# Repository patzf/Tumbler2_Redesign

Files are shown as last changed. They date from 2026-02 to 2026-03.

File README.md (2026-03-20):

# Tumbler 2 `ultra-low-cost`

Single USB port variant of the `Tumbler 2` redesign, optimized for maximum cost reduction.

## Changes

| Original Design | Redesign Improvement |
| --- | --- |
| Unfused battery supply | Add slow-blow fuse directly at connector |
| 5 V to 3.3 V LDO regulator | 5 V to 3.3 V buck converter |
| WROOM module with ESP32-D0WD-V3 | WROOM module with ESP32-S3 |
| CH340 for USB-UART Bridge | Directly connect to ESP32 DP/DN |
| 100 nF capacitors on BTN and GPIO0 | Removed unnecessary capacitors on BTN and GPIO0  |
| USB-C shield directly to signal GND  | Low impedance 100nF to avoid ground loops |
| Use Obsolete MPU6050 breakout module | Use LSM6DSV directly on PCB |
| Use TB6612FNG breakout module | Use 2x TB67H450FNG directly on PCB |
| 5 V ECHO signal directly to ESP32 | Voltage divider to 3.3 V ESP32 GPIO |
| 5 V Encoder signal directly to ESP32 | Voltage divider to 3.3 V ESP32 GPIO |
| No local decoupling for WS2812B LEDs | Added proper local bypass capacitors for WS2812B |

## Discarded Ideas

| Idea | Reason |
| --- | --- |
| On-board charging circuit (IP5306, BQ25887RGER) | Not required. External USB charger included with battery  |
| Additional LDO for clean 3.3 V rail | Not necessary. ESP32-WROOM internal VCC/VCCA already tied |

## Layout Options

| Layout A | Layout B | Layout C |
| --- | --- | --- |
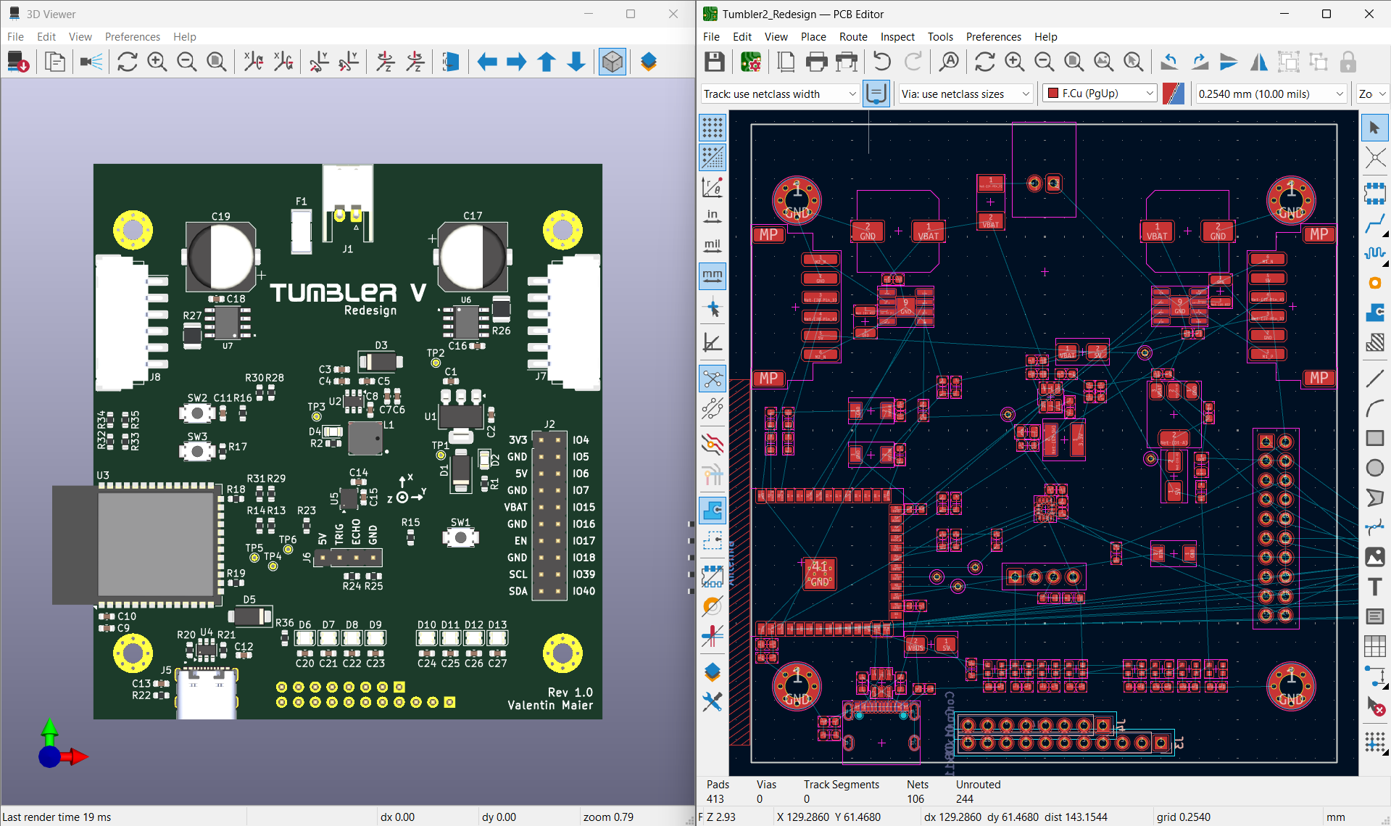
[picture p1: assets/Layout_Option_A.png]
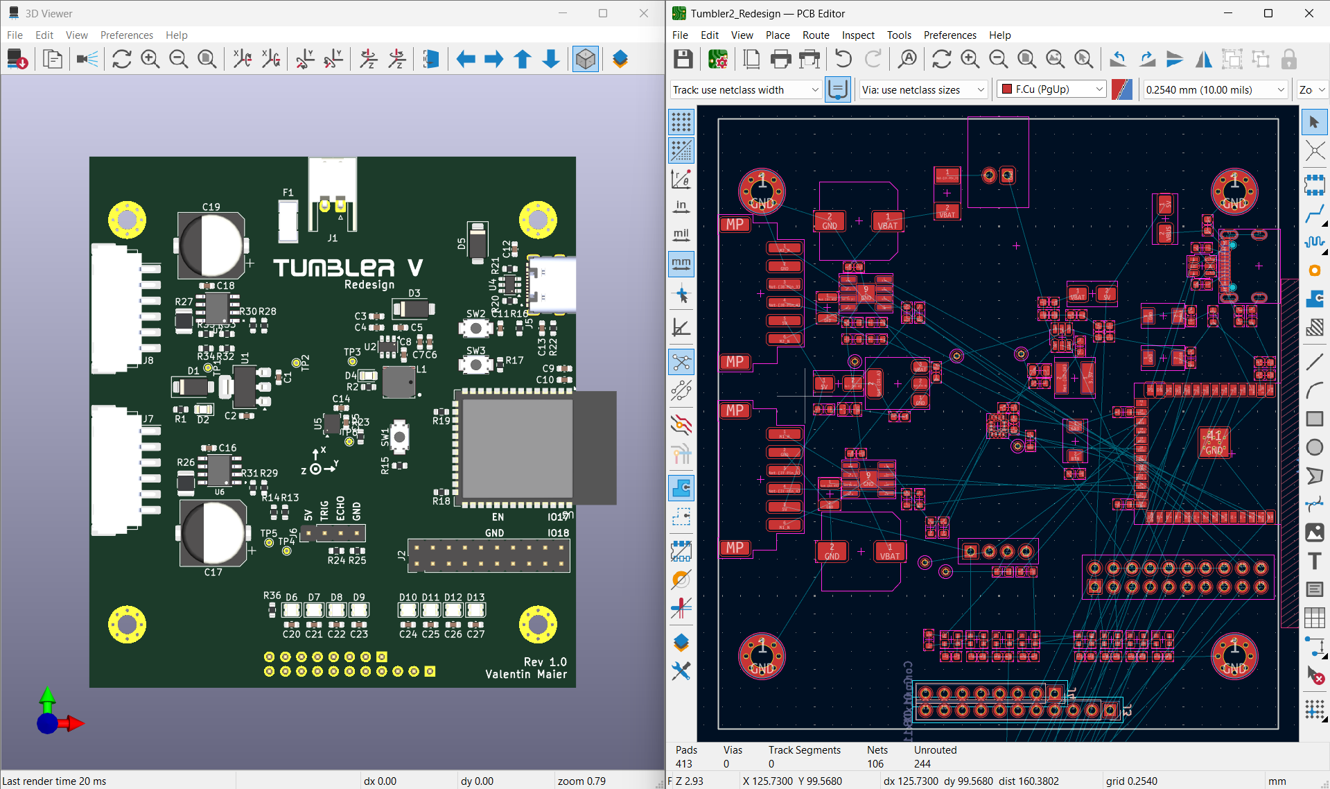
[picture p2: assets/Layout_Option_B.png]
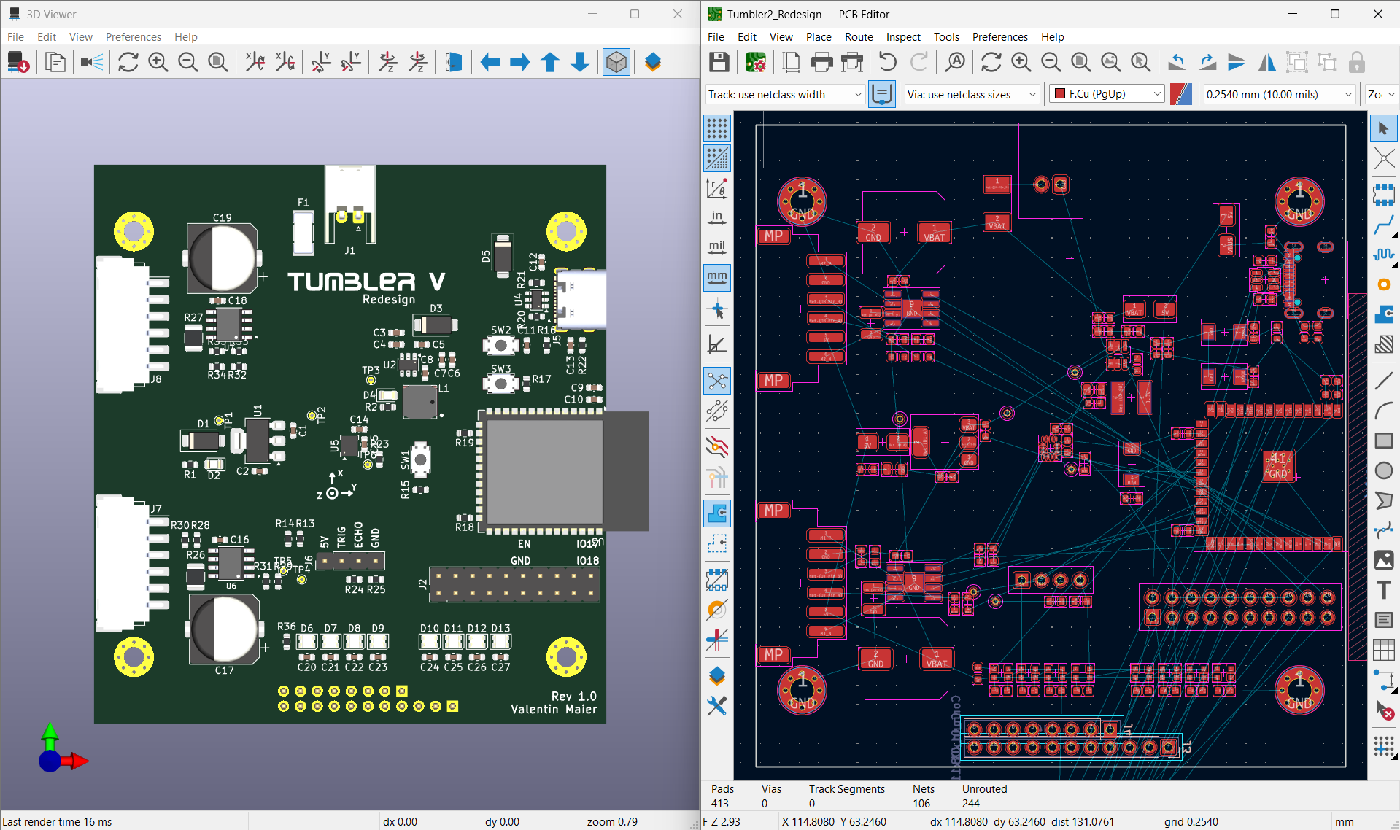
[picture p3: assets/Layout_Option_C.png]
| <br><sub>Preferred option</sub> | <br><sub>Left–right separation</sub> | <br><sub>Looser version of B</sub> |

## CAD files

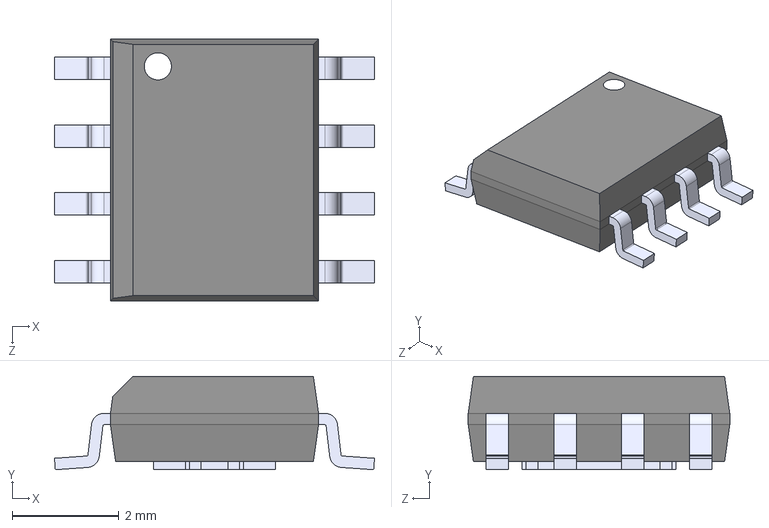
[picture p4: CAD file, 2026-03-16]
Tumbler2_Models/TB67H450FNG_EL.step
6.00 x 1.75 x 4.90 mm

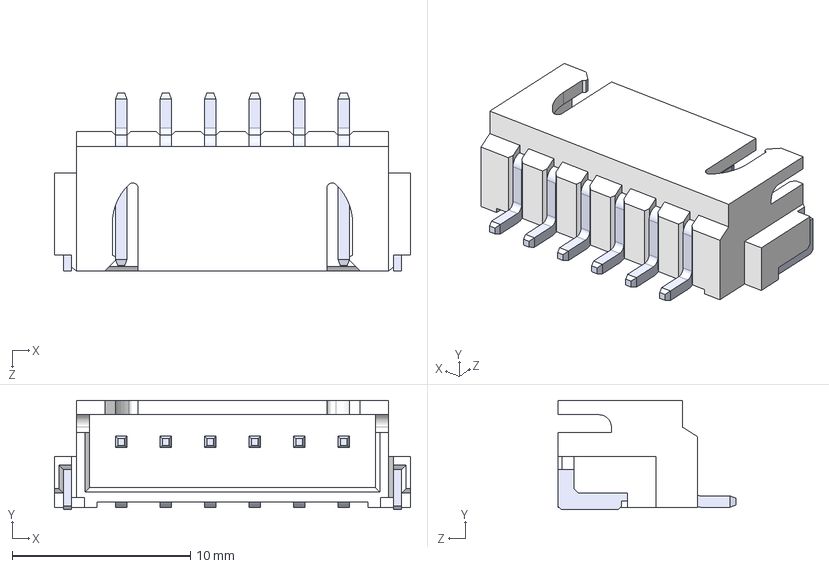
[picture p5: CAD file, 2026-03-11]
Tumbler2_Models/S6B-XH-SM4-TB-LF-SN.step
20.0 x 6.12 x 10.0 mm
SxB-XH-SM4-TB_6
pin^SxB-XH-SM4-TB Ass x 6

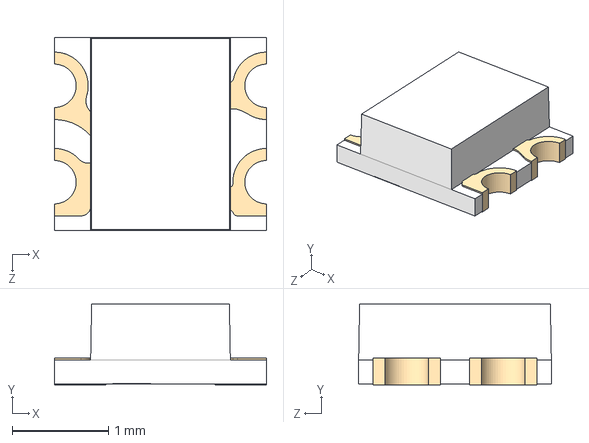
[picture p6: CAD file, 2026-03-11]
Tumbler2_Models/WS2812B-2020.step
2.20 x 0.84 x 2.00 mm

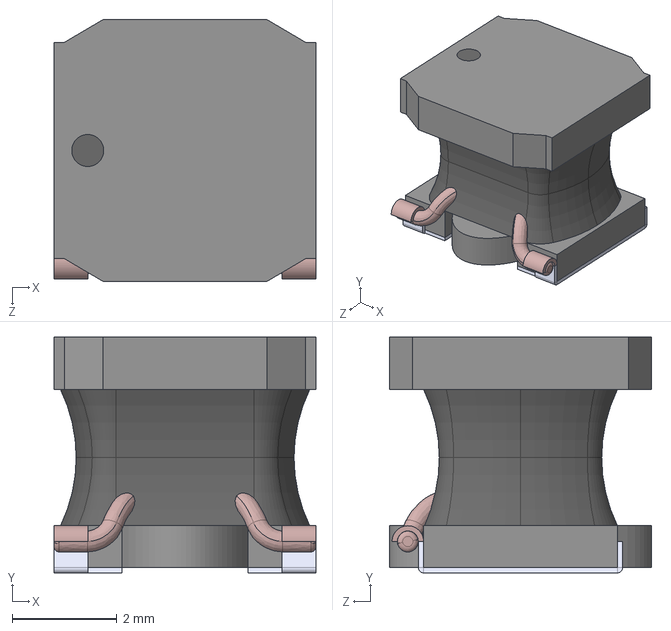
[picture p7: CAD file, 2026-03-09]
Tumbler2_Models/VLS5045EX-4R7M.step
5.00 x 4.50 x 5.00 mm

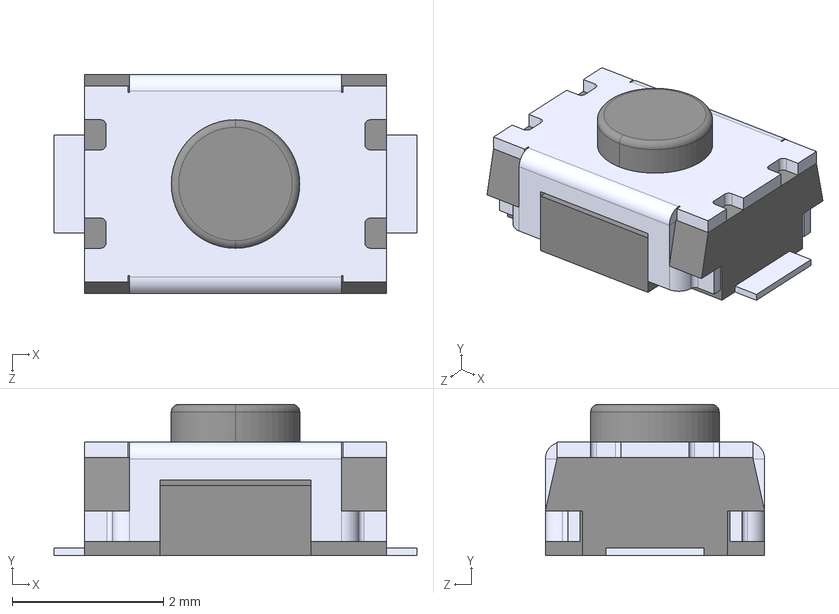
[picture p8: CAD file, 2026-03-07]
Tumbler2_Models/TS-1088-AR02016.step
4.80 x 2.00 x 2.90 mm

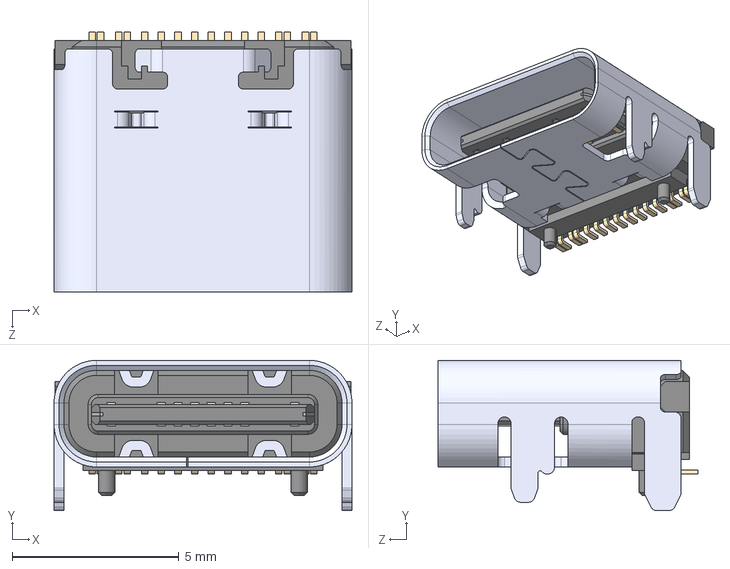
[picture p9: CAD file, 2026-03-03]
Tumbler2_Models/KH-TYPE-C-16P.step
8.94 x 4.51 x 7.81 mm

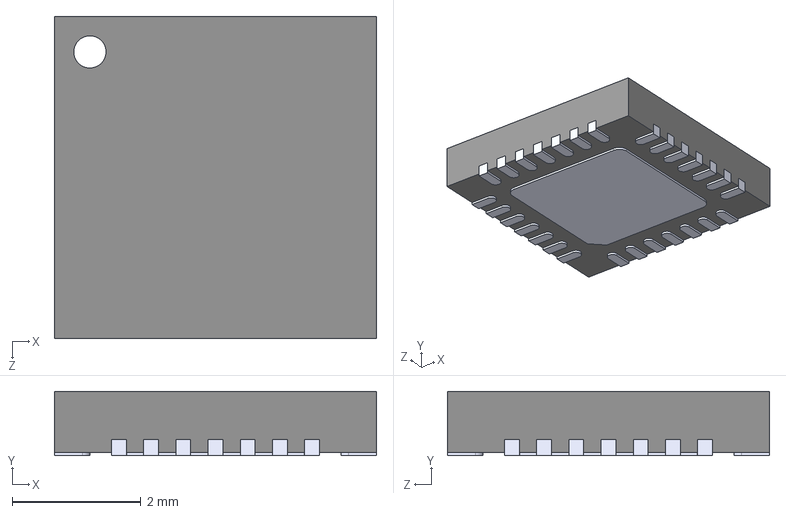
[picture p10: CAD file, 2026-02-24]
Tumbler2_Models/QFN50P500X500X100-29N.step
5.00 x 1.00 x 5.00 mm

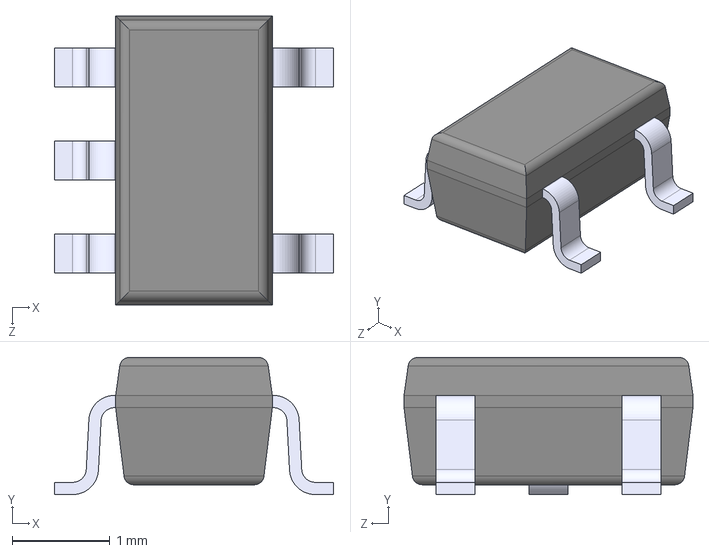
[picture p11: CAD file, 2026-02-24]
Tumbler2_Models/SOT95P285X130-5N.step
2.85 x 1.40 x 2.95 mm

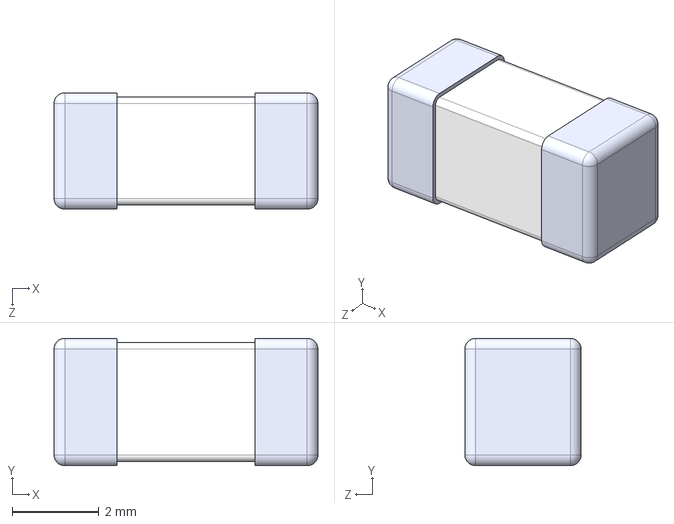
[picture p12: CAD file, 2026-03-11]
Tumbler2_Models/0452005.MRL.step
6.10 x 2.94 x 2.69 mm

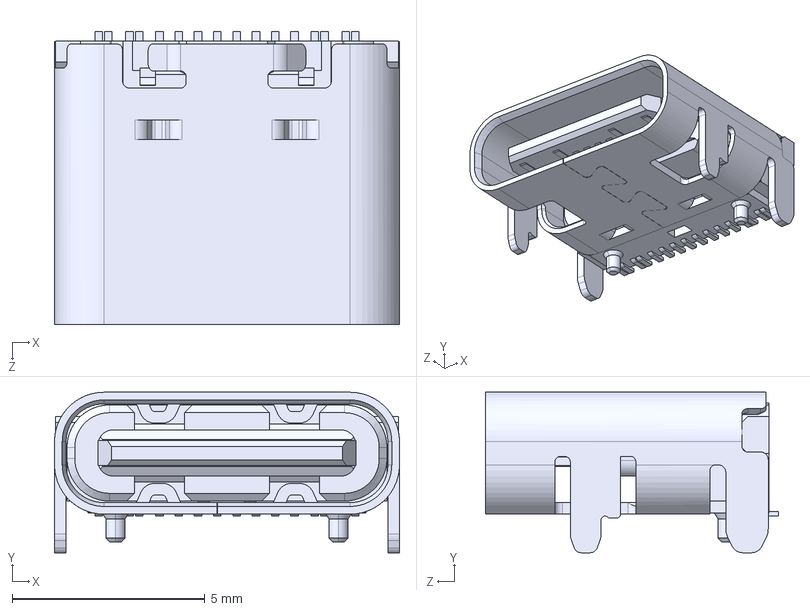
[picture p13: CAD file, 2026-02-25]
Tumbler2_Models/10155435-00011LF.step
8.94 x 4.16 x 7.60 mm

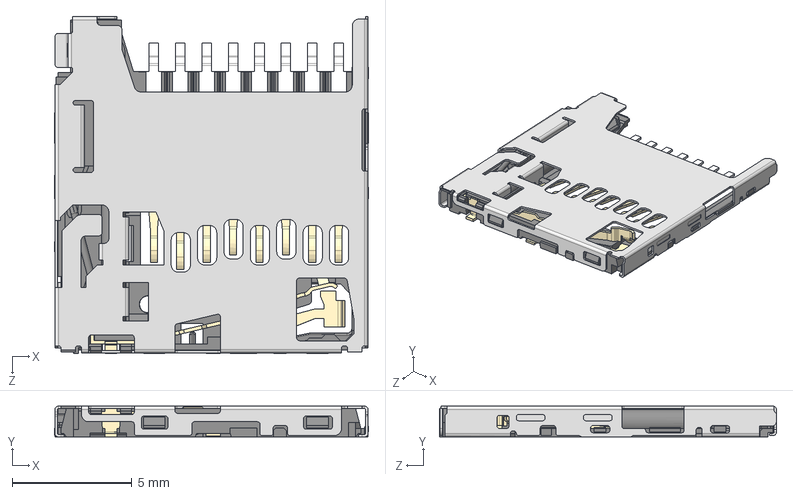
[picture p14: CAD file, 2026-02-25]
Tumbler2_Models/503398-1892.step
13.1 x 1.28 x 14.1 mm

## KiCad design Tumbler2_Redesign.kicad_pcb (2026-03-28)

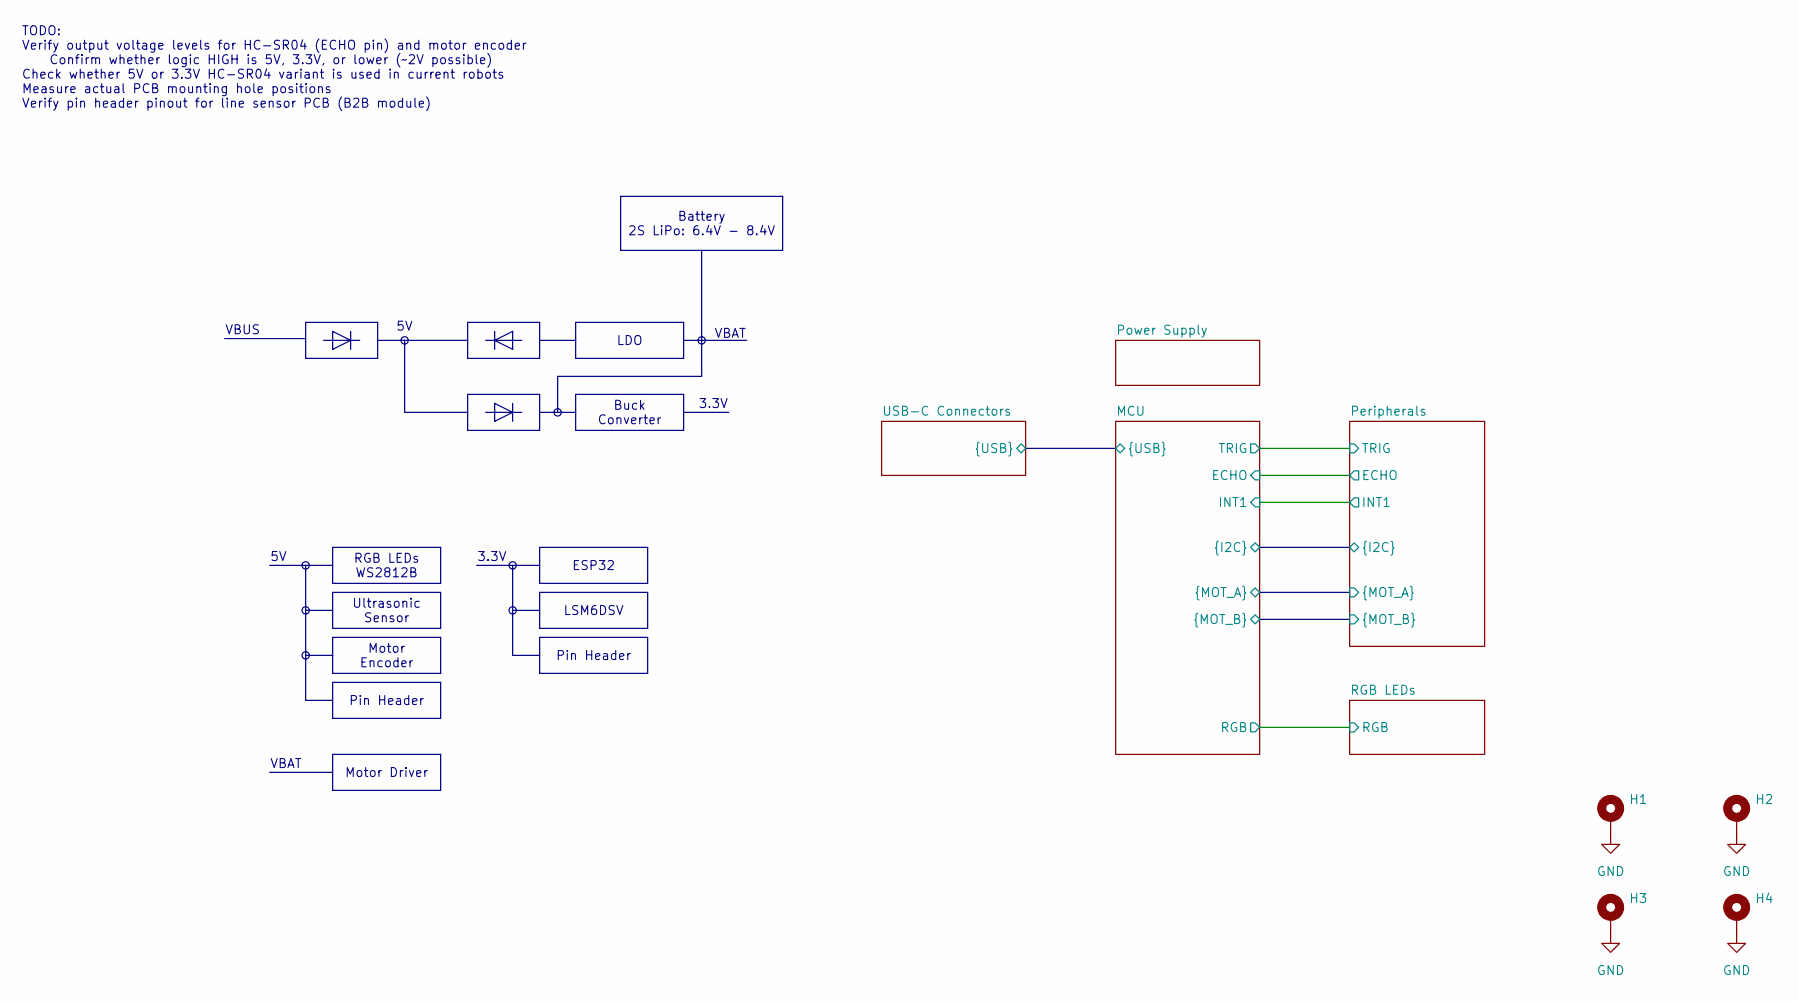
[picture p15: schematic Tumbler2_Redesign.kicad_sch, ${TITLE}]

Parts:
H1, H2, H3, H4: MountingHole_Pad; MountingHole_3mm_Pad_Via

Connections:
GND: H1.1, H2.1, H3.1, H4.1; also elsewhere on the board

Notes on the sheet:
TODO: Verify output voltage levels for HC-SR04 (ECHO pin) and motor encoder Confirm whether logic HIGH is 5V, 3.3V, or lower (~2V possible) Check whether 5V or 3.3V HC-SR04 variant is used in current robots Measure actual PCB mounting hole positions Verify pin header pinout for line sensor PCB (B2B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
VBUS
3.3V
VBAT
Motor Encoder
LSM6DSV
RGB LEDs WS2812B
Motor Driver
Pin Header
Buck Converter
ESP32
Battery 2S LiPo: 6.4V - 8.4V
Ultrasonic Sensor
LDO

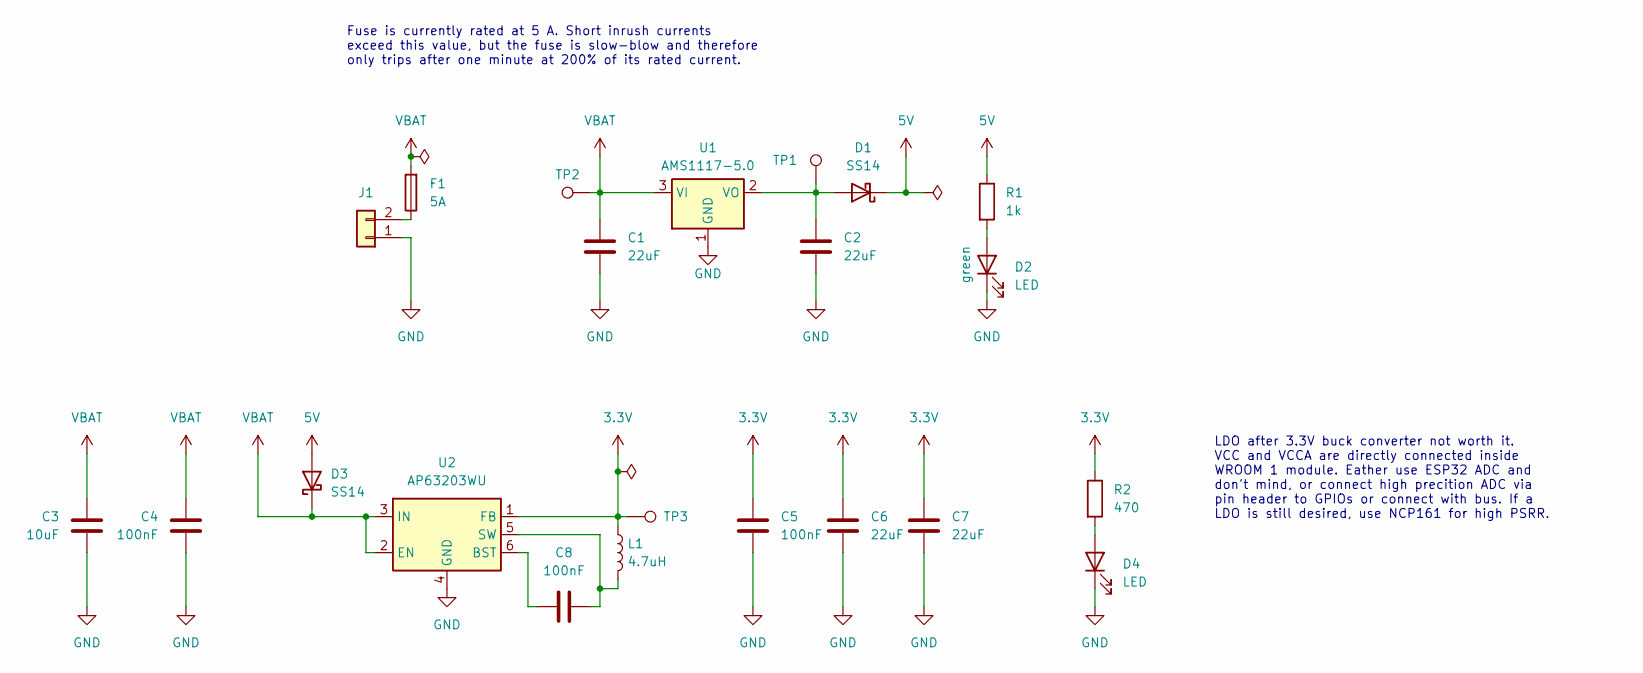
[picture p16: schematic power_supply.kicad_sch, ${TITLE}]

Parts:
C1, C2, C6, C7: 22uF; C_0805_2012Metric; LCSC PN C45783
C3: 10uF; C_0603_1608Metric; LCSC PN C96446
C4, C5, C8: 100nF; C_0603_1608Metric; LCSC PN C14663
D1, D3: SS14; D_SMA; LCSC PN C2480
D2, D4: LED; LED_0805_2012Metric; LCSC PN C2297
F1: 5A; Fuse_Littelfuse-NANO2-451_453; LCSC PN C66503
J1: Conn_01x02; JST_XH_S2B-XH-A-1_1x02_P2.50mm_Horizontal; LCSC PN C163035
L1: 4.7uH; VLS5045EX-4R7M; LCSC PN C307876
R1: 1k; R_0603_1608Metric; LCSC PN C21190
R2: 470; R_0603_1608Metric; LCSC PN C23179
TP1, TP2, TP3: TestPoint; TestPoint_THTPad_D1.0mm_Drill0.5mm
U1: AMS1117-5.0; SOT-223-3_TabPin2; LCSC PN C6187
U2: AP63203WU; TSOT-23-6; LCSC PN C780769

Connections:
3.3V: C5.1, C6.1, C7.1, L1.1, R2.1, TP3.1, U2.1 (FB); also elsewhere on the board
5V: D1.1 (K), D3.2 (A), R1.1; also elsewhere on the board
GND: C1.2, C2.2, C3.2, C4.2, C5.2, C6.2, C7.2, D2.1 (K), D4.1 (K), J1.1, U1.1 (GND), U2.4 (GND); also elsewhere on the board
unnamed: C2.1, D1.2 (A), TP1.1, U1.2 (VO)
unnamed: D2.2 (A), R1.2
unnamed: D4.2 (A), R2.2
unnamed: F1.1, J1.2
unnamed: C8.2, U2.6 (BST)
unnamed: C8.1, L1.2, U2.5 (SW)
VBAT: C1.1, C3.1, C4.1, D3.1 (K), F1.2, TP2.1, U1.3 (VI), U2.2 (EN), U2.3 (IN); also elsewhere on the board

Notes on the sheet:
Fuse is currently rated at 5 A. Short inrush currents exceed this value, but the fuse is slow-blow and therefore only trips after one minute at 200% of its rated current.
LDO after 3.3V buck converter not worth it. VCC and VCCA are directly connected inside WROOM 1 module. Eather use ESP32 ADC and don't mind, or connect high precition ADC via pin header to GPIOs or connect with bus. If a LDO is still desired, use NCP161 for high PSRR.

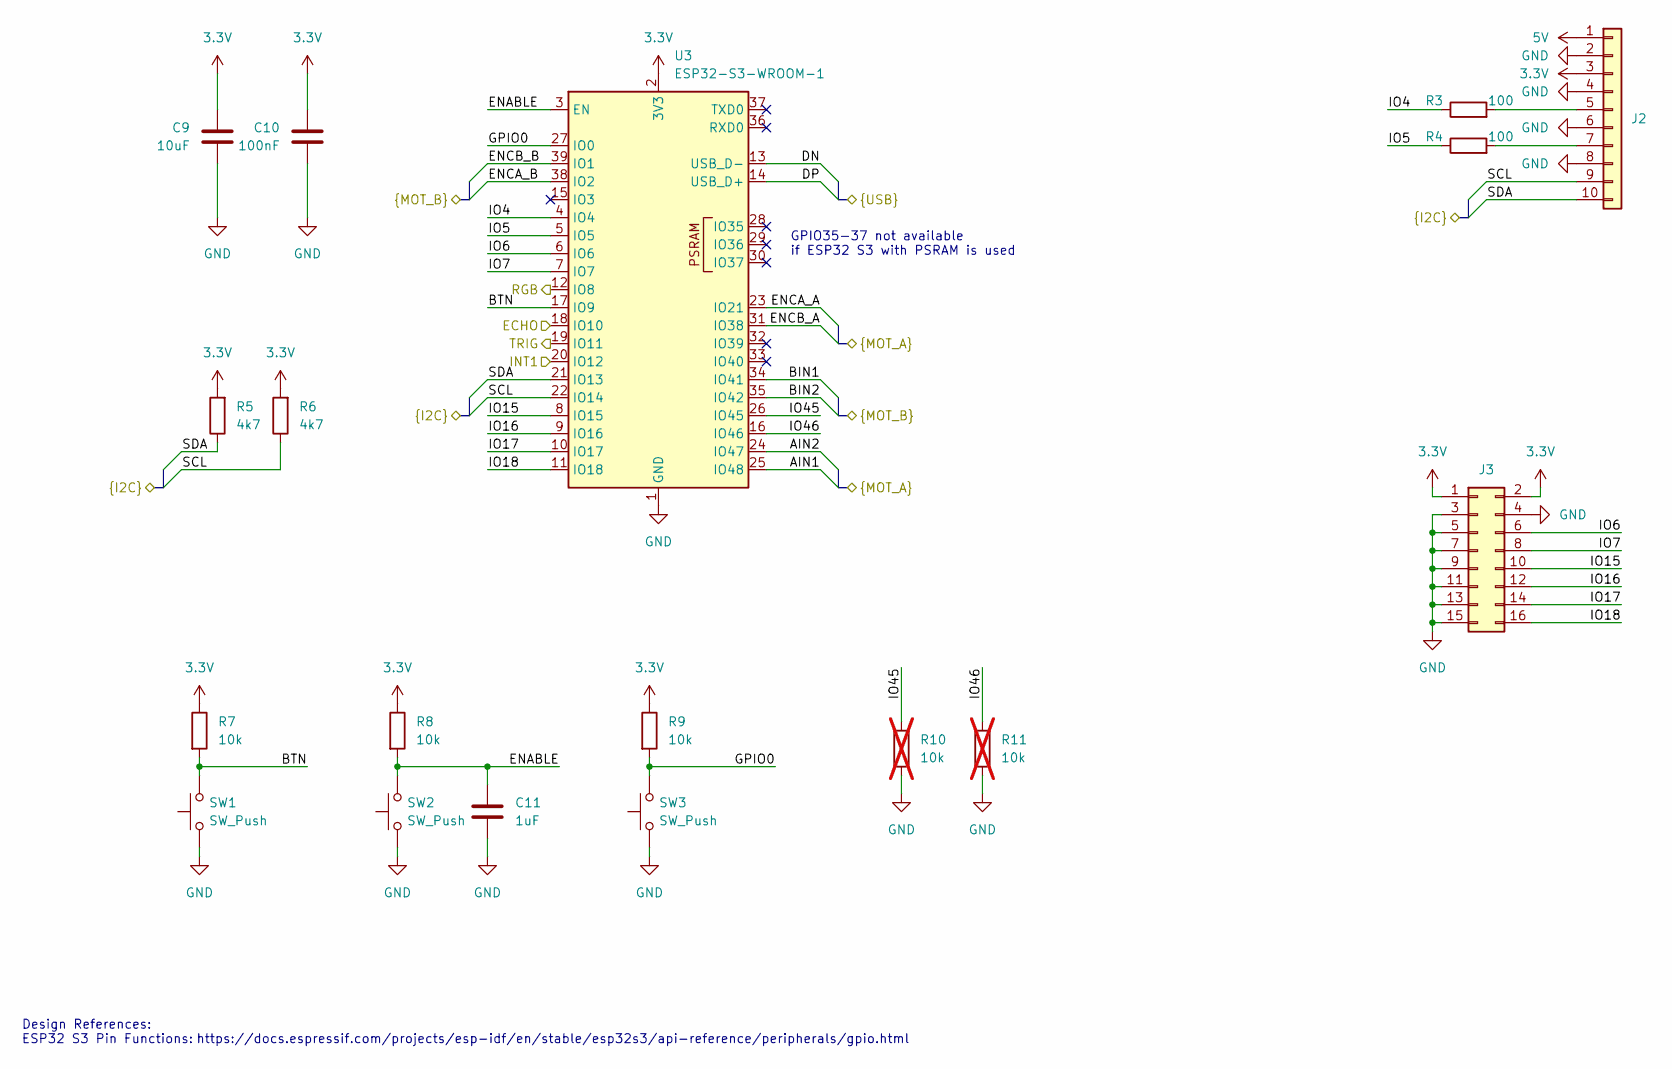
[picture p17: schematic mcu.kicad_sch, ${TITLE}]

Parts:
C9: 10uF; C_0603_1608Metric; LCSC PN C96446
C10: 100nF; C_0603_1608Metric; LCSC PN C14663
C11: 1uF; C_0603_1608Metric; LCSC PN C15849
J2: Conn_01x10; PinHeader_1x10_P2.54mm_Vertical
J3: Conn_02x08_Odd_Even; PinHeader_2x08_P2.54mm_Vertical
R3, R4: 100; R_0603_1608Metric; LCSC PN C22775
R5, R6: 4k7; R_0603_1608Metric; LCSC PN C23162
R7, R8, R9: 10k; R_0603_1608Metric; LCSC PN C25804
R10, R11: 10k; R_0603_1608Metric; LCSC PN C25804; not fitted
SW1, SW2, SW3: SW_Push; SW_TS-1088-AR02016; LCSC PN C720477
U3: ESP32-S3-WROOM-1; LCSC PN C2913202

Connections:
3.3V: C9.1, C10.1, J2.3, J3.1, J3.2, R5.2, R6.2, R7.1, R8.1, R9.1, U3.2 (3V3); also elsewhere on the board
5V: J2.1; also elsewhere on the board
/MCU/AIN1: U3.25 (IO48); also elsewhere on the board
/MCU/AIN2: U3.24 (IO47); also elsewhere on the board
/MCU/BIN1: U3.34 (IO41); also elsewhere on the board
/MCU/BIN2: U3.35 (IO42); also elsewhere on the board
/MCU/BTN: R7.2, SW1.2, U3.17 (IO9)
/MCU/DN: U3.13 (USB_D-); also elsewhere on the board
/MCU/DP: U3.14 (USB_D+); also elsewhere on the board
/MCU/ECHO: U3.18 (IO10); also elsewhere on the board
/MCU/ENABLE: C11.1, R8.2, SW2.2, U3.3 (EN)
/MCU/ENCA_A: U3.23 (IO21); also elsewhere on the board
/MCU/ENCA_B: U3.38 (IO2); also elsewhere on the board
/MCU/ENCB_A: U3.31 (IO38); also elsewhere on the board
/MCU/ENCB_B: U3.39 (IO1); also elsewhere on the board
/MCU/GPIO0: R9.2, SW3.2, U3.27 (IO0)
/MCU/INT1: U3.20 (IO12); also elsewhere on the board
/MCU/IO4: R3.1, U3.4 (IO4)
/MCU/IO5: R4.1, U3.5 (IO5)
/MCU/IO6: J3.6, U3.6 (IO6)
/MCU/IO7: J3.8, U3.7 (IO7)
/MCU/IO15: J3.10, U3.8 (IO15)
/MCU/IO16: J3.12, U3.9 (IO16)
/MCU/IO17: J3.14, U3.10 (IO17)
/MCU/IO18: J3.16, U3.11 (IO18)
/MCU/IO45: R10.1, U3.26 (IO45)
/MCU/IO46: R11.1, U3.16 (IO46)
/MCU/RGB: U3.12 (IO8); also elsewhere on the board
/MCU/SCL: J2.9, R6.1, U3.22 (IO14); also elsewhere on the board
/MCU/SDA: J2.10, R5.1, U3.21 (IO13); also elsewhere on the board
/MCU/TRIG: U3.19 (IO11); also elsewhere on the board
GND: C9.2, C10.2, C11.2, J2.2, J2.4, J2.6, J2.8, J3.3, J3.4, J3.5, J3.7, J3.9, J3.11, J3.13, J3.15, R10.2, R11.2, SW1.1, SW2.1, SW3.1, U3.1 (GND), U3.40 (GND), U3.41 (GND); also elsewhere on the board
unnamed: J2.5, R3.2
unnamed: J2.7, R4.2

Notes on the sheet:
GPIO35-37 not available if ESP32 S3 with PSRAM is used
Design References: ESP32 S3 Pin Functions:
https://docs.espressif.com/projects/esp-idf/en/stable/esp32s3/api-reference/peripherals/gpio.html

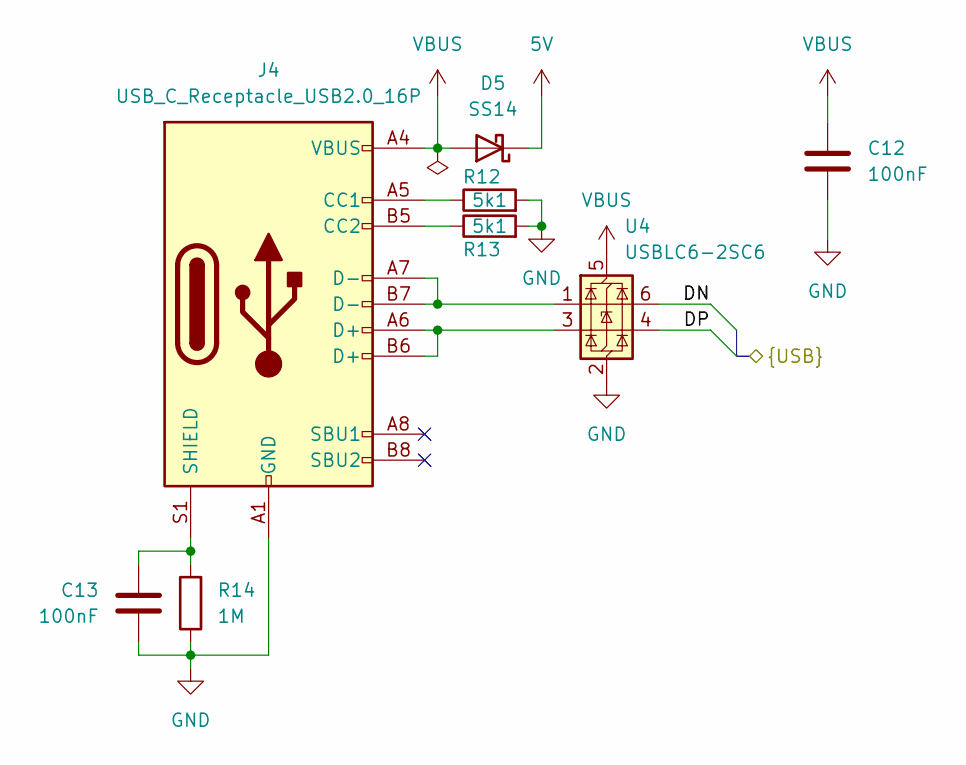
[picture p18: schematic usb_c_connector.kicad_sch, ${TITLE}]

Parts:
C12, C13: 100nF; C_0603_1608Metric; LCSC PN C14663
D5: SS14; D_SMA; LCSC PN C2480
J4: USB_C_Receptacle_USB2.0_16P; KINGHELM_KH-TYPE-C-16P; LCSC PN C709357
R12, R13: 5k1; R_0603_1608Metric; LCSC PN C23186
R14: 1M; R_0603_1608Metric; LCSC PN C22935
U4: USBLC6-2SC6; SOT-23-6; LCSC PN C7519

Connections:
5V: D5.1 (K); also elsewhere on the board
/MCU/DN: U4.6 (I/O1); also elsewhere on the board
/MCU/DP: U4.4 (I/O2); also elsewhere on the board
GND: C12.2, C13.2, J4.A1 (GND), J4.A12 (GND), J4.B1 (GND), J4.B12 (GND), R12.2, R13.2, R14.1, U4.2 (GND); also elsewhere on the board
unnamed: J4.A5 (CC1), R12.1
unnamed: J4.B5 (CC2), R13.1
unnamed: J4.A6 (D+), J4.B6 (D+), U4.3 (I/O2)
unnamed: J4.A7 (D-), J4.B7 (D-), U4.1 (I/O1)
unnamed: C13.1, J4.S1 (SHIELD), R14.2
VBUS: C12.1, D5.2 (A), J4.A4 (VBUS), J4.A9 (VBUS), J4.B4 (VBUS), J4.B9 (VBUS), U4.5 (VBUS)

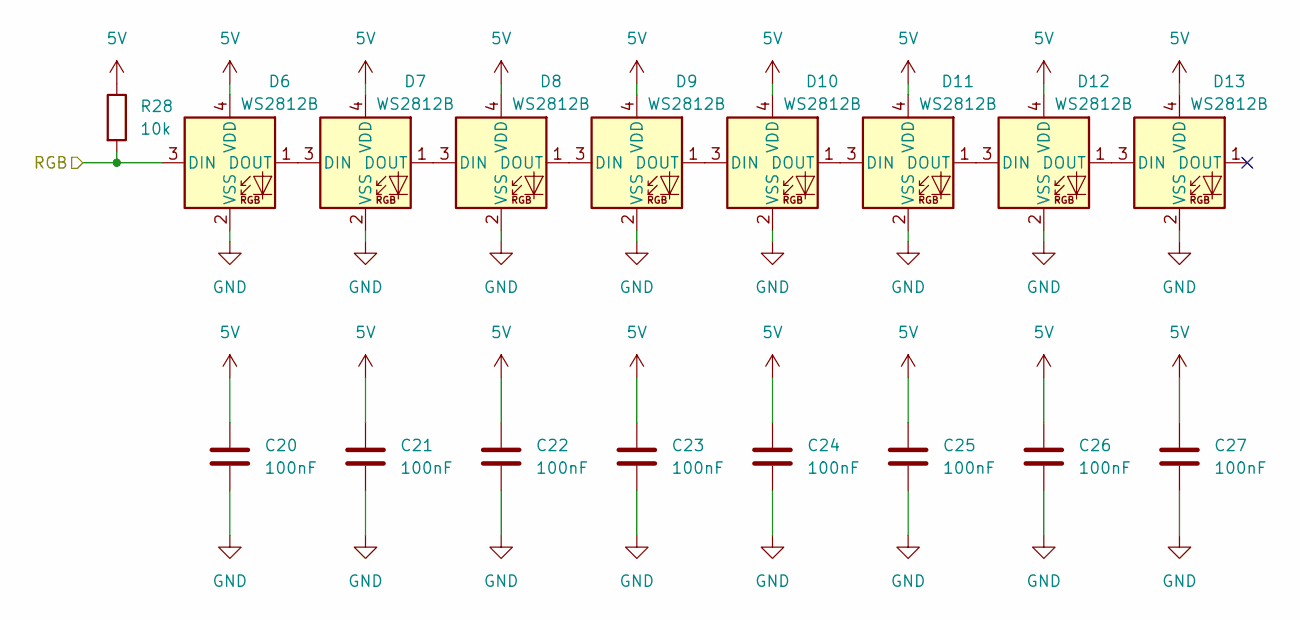
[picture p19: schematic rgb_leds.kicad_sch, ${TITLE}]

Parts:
C20, C21, C22, C23, C24, C25, C26, C27: 100nF; C_0603_1608Metric; LCSC PN C14663
D6, D7, D8, D9, D10, D11, D12, D13: WS2812B; LED_WS2812B-2020_PLCC4_2.0x2.0mm; LCSC PN C965555
R28: 10k; R_0603_1608Metric; LCSC PN C25804

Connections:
5V: C20.1, C21.1, C22.1, C23.1, C24.1, C25.1, C26.1, C27.1, D6.4 (VDD), D7.4 (VDD), D8.4 (VDD), D9.4 (VDD), D10.4 (VDD), D11.4 (VDD), D12.4 (VDD), D13.4 (VDD), R28.1; also elsewhere on the board
/MCU/RGB: D6.3 (DIN), R28.2; also elsewhere on the board
GND: C20.2, C21.2, C22.2, C23.2, C24.2, C25.2, C26.2, C27.2, D6.2 (VSS), D7.2 (VSS), D8.2 (VSS), D9.2 (VSS), D10.2 (VSS), D11.2 (VSS), D12.2 (VSS), D13.2 (VSS); also elsewhere on the board
unnamed: D6.1 (DOUT), D7.3 (DIN)
unnamed: D7.1 (DOUT), D8.3 (DIN)
unnamed: D8.1 (DOUT), D9.3 (DIN)
unnamed: D9.1 (DOUT), D10.3 (DIN)
unnamed: D10.1 (DOUT), D11.3 (DIN)
unnamed: D11.1 (DOUT), D12.3 (DIN)
unnamed: D12.1 (DOUT), D13.3 (DIN)

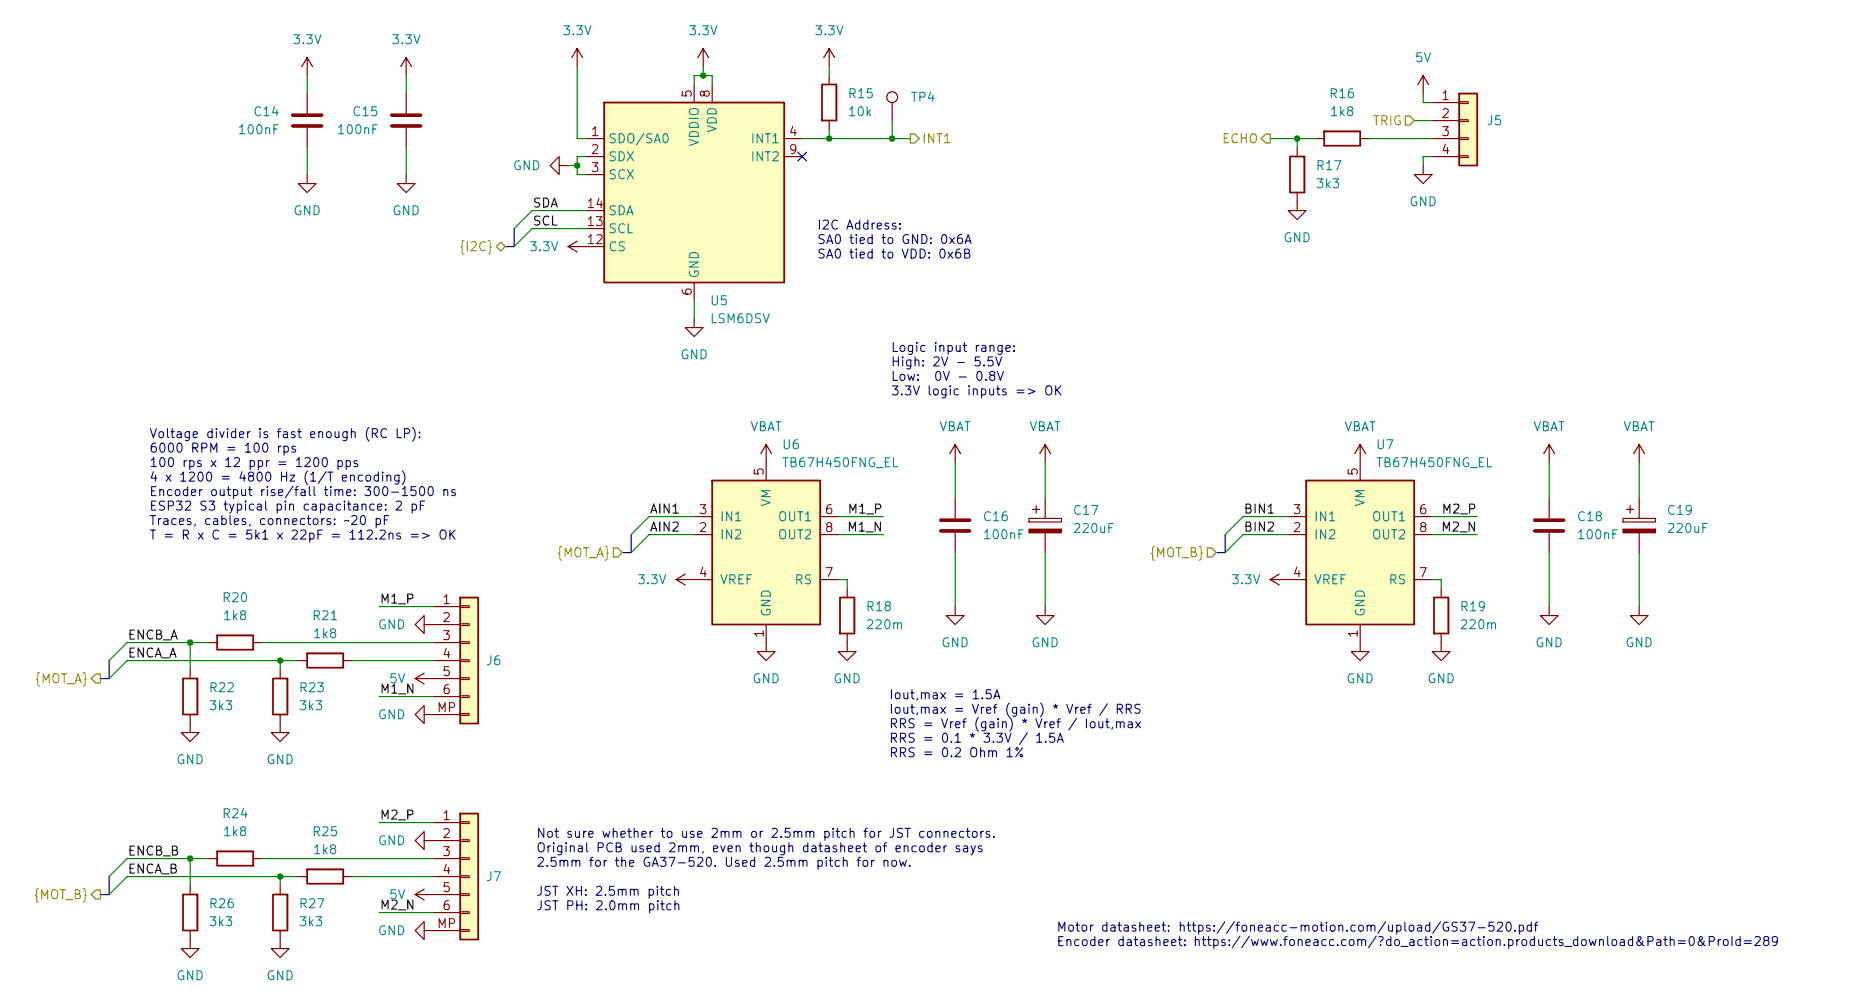
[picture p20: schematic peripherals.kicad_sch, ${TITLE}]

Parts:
C14, C15, C16, C18: 100nF; C_0603_1608Metric; LCSC PN C14663
C17, C19: 220uF; CP_Elec_10x10; LCSC PN C250054
J5: Conn_01x04; PinHeader_1x04_P2.54mm_Vertical; LCSC PN C5116530
J6, J7: Conn_01x06; JST_XH_S6B-XH-SM4-TB_1x06-1MP_P2.50mm_Horizontal; LCSC PN C191914
R15: 10k; R_0603_1608Metric; LCSC PN C25804
R16, R20, R21, R24, R25: 1k8; R_0603_1608Metric; LCSC PN C4177
R17, R22, R23, R26, R27: 3k3; R_0603_1608Metric; LCSC PN C22978
R18, R19: 220m; R_1210_3225Metric; LCSC PN C2934313
TP4: TestPoint; TestPoint_THTPad_D1.0mm_Drill0.5mm
U5: LSM6DSV; LGA-14_3x2.5mm_P0.5mm_LayoutBorder3x4y; LCSC PN C41785564
U6, U7: TB67H450FNG_EL; SOIC127P599X175-9N; LCSC PN C545417

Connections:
3.3V: C14.1, C15.1, R15.1, U5.1 (SDO/SA0), U5.5 (VDDIO), U5.8 (VDD), U5.12 (CS), U6.4 (VREF), U7.4 (VREF); also elsewhere on the board
5V: J5.1, J6.5, J7.5; also elsewhere on the board
/MCU/AIN1: U6.3 (IN1); also elsewhere on the board
/MCU/AIN2: U6.2 (IN2); also elsewhere on the board
/MCU/BIN1: U7.3 (IN1); also elsewhere on the board
/MCU/BIN2: U7.2 (IN2); also elsewhere on the board
/MCU/ECHO: R16.2, R17.2; also elsewhere on the board
/MCU/ENCA_A: R21.2, R23.2; also elsewhere on the board
/MCU/ENCA_B: R25.2, R27.2; also elsewhere on the board
/MCU/ENCB_A: R20.2, R22.2; also elsewhere on the board
/MCU/ENCB_B: R24.2, R26.2; also elsewhere on the board
/MCU/INT1: R15.2, TP4.1, U5.4 (INT1); also elsewhere on the board
/MCU/SCL: U5.13 (SCL); also elsewhere on the board
/MCU/SDA: U5.14 (SDA); also elsewhere on the board
/MCU/TRIG: J5.2; also elsewhere on the board
/Peripherals/M1_N: J6.6, U6.8 (OUT2)
/Peripherals/M1_P: J6.1, U6.6 (OUT1)
/Peripherals/M2_N: J7.6, U7.8 (OUT2)
/Peripherals/M2_P: J7.1, U7.6 (OUT1)
GND: C14.2, C15.2, C16.2, C17.2, C18.2, C19.2, J5.4, J6.2, J6.MP, J7.2, J7.MP, R17.1, R18.2, R19.2, R22.1, R23.1, R26.1, R27.1, U5.2 (SDX), U5.3 (SCX), U5.6 (GND), U5.7 (GND), U6.1 (GND), U6.9 (GND), U7.1 (GND), U7.9 (GND); also elsewhere on the board
unnamed: J5.3, R16.1
unnamed: J6.3, R20.1
unnamed: J6.4, R21.1
unnamed: J7.3, R24.1
unnamed: J7.4, R25.1
unnamed: R18.1, U6.7 (RS)
unnamed: R19.1, U7.7 (RS)
VBAT: C16.1, C17.1, C18.1, C19.1, U6.5 (VM), U7.5 (VM); also elsewhere on the board

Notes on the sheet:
I2C Address: SA0 tied to GND: 0x6A SA0 tied to VDD: 0x6B
Motor datasheet: Encoder datasheet:
https://foneacc-motion.com/upload/GS37-520.pdf
https://www.foneacc.com/?do_action=action.products_download&Path=0&ProId=289
Not sure whether to use 2mm or 2.5mm pitch for JST connectors. Original PCB used 2mm, even though datasheet of encoder says 2.5mm for the GA37-520. Used 2.5mm pitch for now. JST XH: 2.5mm pitch JST PH: 2.0mm pitch
Iout,max = 1.5A Iout,max = Vref (gain) * Vref / RRS RRS = Vref (gain) * Vref / Iout,max RRS = 0.1 * 3.3V / 1.5A RRS = 0.2 Ohm 1%
Voltage divider is fast enough (RC LP): 6000 RPM = 100 rps 100 rps x 12 ppr = 1200 pps 4 x 1200 = 4800 Hz (1/T encoding) Encoder output rise/fall time: 300-1500 ns ESP32 S3 typical pin capacitance: 2 pF Traces, cables, connectors: ~20 pF T = R x C = 5k1 x 22pF = 112.2ns => OK
Logic input range: High: 2V - 5.5V Low: 0V - 0.8V 3.3V logic inputs => OK

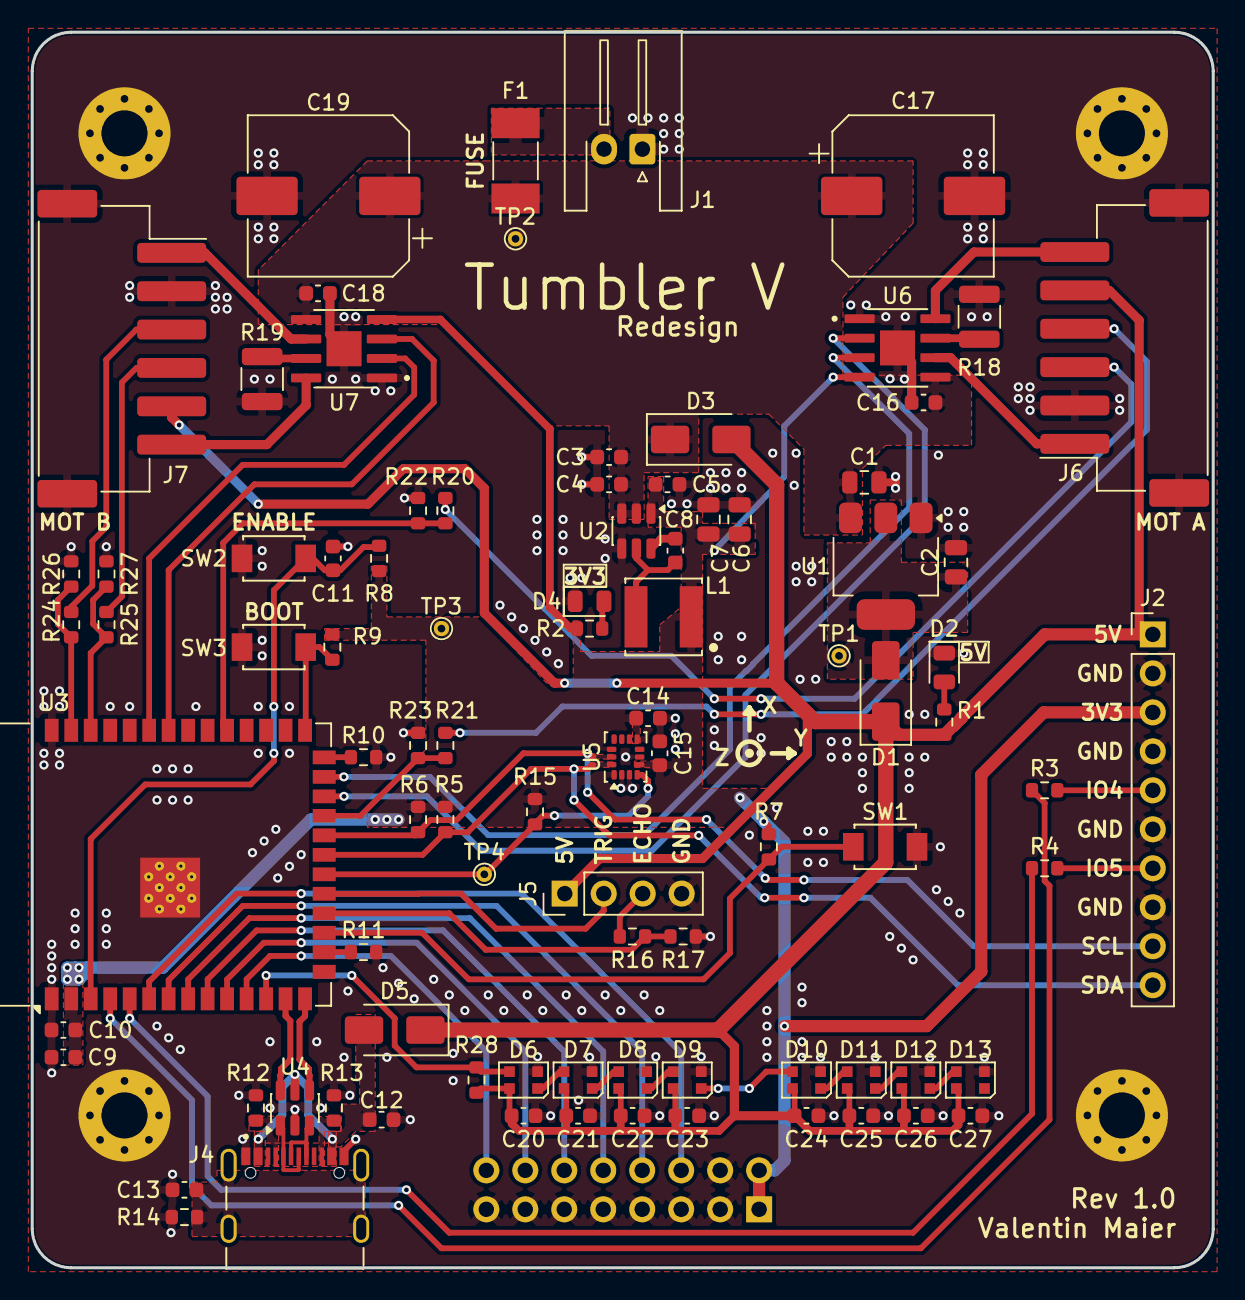
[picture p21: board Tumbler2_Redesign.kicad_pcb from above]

Board: 2 copper layers, 77.0 x 80.5 mm, 95 parts (1 on the bottom side), 65 nets.

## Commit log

2026-02-23 Add empty KiCad project
    [Tumbler2_Redesign.kicad_pcb, Tumbler2_Redesign.kicad_sch]
2026-02-23 Add ESP32 and USB
    [Tumbler2_Redesign.kicad_sch]
2026-02-23 Add further parts
    [Tumbler2_Redesign.kicad_pcb, Tumbler2_Redesign.kicad_sch]
2026-02-24 Add regulators and USB to UART
    [QFN50P500X500X100-29N.step, SOT95P285X130-5N.step, Tumbler2_Redesign.kicad_sch]
2026-02-24 Remove overcurrent protection
    [Tumbler2_Redesign.kicad_sch]
2026-02-24 Add IMU and motor driver
    [Tumbler2_Redesign.kicad_sch]
2026-02-25 Move to hierarchical design
    [10155435-00011LF.step, 503398-1892.step, Tumbler2_Redesign.kicad_sch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]
2026-02-26 Replace schottky with ideal diode
    [Tumbler2_Redesign.kicad_sch, mcu.kicad_sch, motor_driver.kicad_sch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]
2026-02-26 Update TODO entries
    [Tumbler2_Redesign.kicad_sch, mcu.kicad_sch, motor_driver.kicad_sch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]
2026-02-26 Follow DC-DC typical application
    [Tumbler2_Redesign.kicad_sch, mcu.kicad_sch, motor_driver.kicad_sch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]
2026-02-26 Add test points
    [mcu.kicad_sch, motor_driver.kicad_sch, pin_headers.kicad_sch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]
2026-02-26 Reset PCB and lock mounting holes
    [Tumbler2_Redesign.kicad_pcb, mcu.kicad_sch, motor_driver.kicad_sch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]
2026-03-02 Assign footprints
    [mcu.kicad_sch, motor_driver.kicad_sch, pin_headers.kicad_sch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]
2026-03-02 Update LCSC symbol field
    [mcu.kicad_sch, pin_headers.kicad_sch, power_supply.kicad_sch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]
2026-03-02 Assign LCSC part numbers
    [mcu.kicad_sch, motor_driver.kicad_sch, power_supply.kicad_sch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]
2026-03-02 Add datasheet including schematics
2026-03-02 Reason about 3V3 LDO
    [power_supply.kicad_sch]
2026-03-02 Prepare for IMU replacement
    [Tumbler2_Redesign.kicad_sch, sensors.kicad_sch]
2026-03-03 Move lists to README
    [Tumbler2_Redesign.kicad_sch]
2026-03-03 Undo component replacement
    [Tumbler2_Redesign.kicad_sch, mcu.kicad_sch, pin_headers.kicad_sch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]
2026-03-03 Use cheaper USB-C connector
    [KH-TYPE-C-16P.step, usb_c_connector.kicad_sch]
2026-03-03 Document address assignment
    [sensors.kicad_sch]
2026-03-04 Connect motor driver lines
    [mcu.kicad_sch]
2026-03-04 Use correct connector footprint
    [motor_driver.kicad_sch]
2026-03-04 Add battery connector
    [power_supply.kicad_sch]
2026-03-04 Fix sensor wiring
    [Tumbler2_Redesign.kicad_sch, sensors.kicad_sch]
2026-03-04 Add HC-SR04 3D model
    [Tumbler2_Redesign.kicad_pcb]
2026-03-04 Add missing pull-up for CP2102
    [mcu.kicad_sch, motor_driver.kicad_sch, power_supply.kicad_sch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]
2026-03-04 Remove caps for BTN and GPIO0
    [mcu.kicad_sch, motor_driver.kicad_sch, sensors.kicad_sch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]
2026-03-04 Finish top level wiring
    [Tumbler2_Redesign.kicad_sch]
2026-03-04 Correct pin header rotation
    [Tumbler2_Redesign.kicad_pcb]
2026-03-04 Add missing bus pull-ups
    [mcu.kicad_sch, motor_driver.kicad_sch, sensors.kicad_sch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]
2026-03-04 Add expansion pin headers
    [Tumbler2_Redesign.kicad_pcb, Tumbler2_Redesign.kicad_sch, mcu.kicad_sch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]
2026-03-04 Combine peripheral modules
    [Tumbler2_Redesign.kicad_sch, mcu.kicad_sch, motor_driver.kicad_sch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]
2026-03-05 Correct voltage level translation
    [Tumbler2_Redesign.kicad_pcb, Tumbler2_Redesign.kicad_sch, mcu.kicad_sch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]
2026-03-05 Remove polyfuse as not necessary
    [usb_c_connector.kicad_sch]
2026-03-05 Replace polyfuse with tube fuse
    [peripherals.kicad_sch, power_supply.kicad_sch]
2026-03-05 Break out ADC and touch pins
    [Tumbler2_Redesign.kicad_sch, mcu.kicad_sch, peripherals.kicad_sch]
2026-03-05 Assign fuse clips and add fuse to BOM
    [power_supply.kicad_sch]
2026-03-06 Move fuse to correct location
    [mcu.kicad_sch, peripherals.kicad_sch, power_supply.kicad_sch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]
2026-03-07 Assign footprints and parts
    [TS-1088-AR02016.step, Tumbler2_Redesign.kicad_pcb, mcu.kicad_sch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]
2026-03-09 Assign inductor parts
    [VLS5045EX-4R7M.step, power_supply.kicad_sch]
2026-03-09 De-cascade buck converters
    [mcu.kicad_sch, peripherals.kicad_sch, power_supply.kicad_sch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]
2026-03-09 Suggest LDO if desired
    [power_supply.kicad_sch]
2026-03-09 Break out motor encoder signals
    [mcu.kicad_sch, peripherals.kicad_sch, usb_c_connector.kicad_sch]
2026-03-09 Add test points for ultrasonic sensor
    [peripherals.kicad_sch]
2026-03-09 Add additional bulk cap for motors
    [peripherals.kicad_sch]
2026-03-09 Set footprint for test points
    [peripherals.kicad_sch]
2026-03-09 Fix net connection bug
    [peripherals.kicad_sch]
2026-03-09 Add components to layout
    [Tumbler2_Redesign.kicad_pcb]
2026-03-09 Make lcsc field compatible with plugin
    [Tumbler2_Redesign.kicad_pcb, mcu.kicad_sch, peripherals.kicad_sch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]
2026-03-09 Exclude test points from BOM
    [mcu.kicad_sch, peripherals.kicad_sch, power_supply.kicad_sch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]
2026-03-09 Add missing rgb leds
    [Tumbler2_Redesign.kicad_pcb, Tumbler2_Redesign.kicad_sch, mcu.kicad_sch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]
2026-03-09 Add power rail block diagram
    [Tumbler2_Redesign.kicad_sch, rgb_leds.kicad_sch]
2026-03-10 Replace with cheaper components
    [Tumbler2_Redesign.kicad_sch, mcu.kicad_sch, peripherals.kicad_sch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]
2026-03-10 Replace IMU with modern alternative
    [peripherals.kicad_sch]
2026-03-10 Remove unused symbol field
    [Tumbler2_Redesign.kicad_sch, mcu.kicad_sch, peripherals.kicad_sch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]
2026-03-10 Use basic parts where possible
    [Tumbler2_Redesign.kicad_pcb, mcu.kicad_sch, peripherals.kicad_sch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]
2026-03-10 Group components
    [Tumbler2_Redesign.kicad_pcb]
2026-03-11 Sketch out component placement
    [0452005.MRL.step, S6B-XH-SM4-TB-LF-SN.step, Tumbler2_Redesign.kicad_pcb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]
2026-03-11 Fix bus merging and add net classes
    [Tumbler2_Redesign.kicad_pcb, Tumbler2_Redesign.kicad_sch, mcu.kicad_sch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]
2026-03-12 Start conceptual layouting
    [Tumbler2_Redesign.kicad_pcb, mcu.kicad_sch, peripherals.kicad_sch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]
2026-03-16 Continue layout and update schematic
    [TB67H450FNG_EL.step, Tumbler2_Redesign.kicad_pcb, Tumbler2_Redesign.kicad_sch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]
2026-03-17 Continue layout and add pin header protection
    [Tumbler2_Redesign.kicad_pcb, Tumbler2_Redesign.kicad_sch, mcu.kicad_sch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]
2026-03-18 Add linesensor pin header
    [Tumbler2_Redesign.kicad_pcb, mcu.kicad_sch]
2026-03-19 Document strapping pins
    [Tumbler2_Redesign.kicad_pcb, Tumbler2_Redesign.kicad_sch, mcu.kicad_sch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]
2026-03-24 Connect remaining tracks
    [Tumbler2_Redesign.kicad_pcb, mcu.kicad_sch, peripherals.kicad_sch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]
2026-03-24 Solve some DRC errors and warnings
    [Tumbler2_Redesign.kicad_pcb]
2026-03-24 Prepare for fabrication
    [Tumbler2_Redesign.kicad_pcb]
2026-03-24 Add todo list and update block diagram
    [Tumbler2_Redesign.kicad_pcb, Tumbler2_Redesign.kicad_sch, mcu.kicad_sch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]
2026-03-28 cleanup schemati, replaced some caps from 0603 to 0805 around Linear Regulator
    [Tumbler2_Redesign.kicad_pcb, Tumbler2_Redesign.kicad_sch, mcu.kicad_sch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]
